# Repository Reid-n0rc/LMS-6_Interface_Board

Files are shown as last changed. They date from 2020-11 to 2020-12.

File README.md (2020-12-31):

# LMS-6_Interface_Board
Interface to the LMS-6 radiosonde carde edge connector.

This project provides an easy way to connect to the UARTs, in circuit programming of the ST7, and provide power to the LMS6 Radiosonde using a card edge connector.
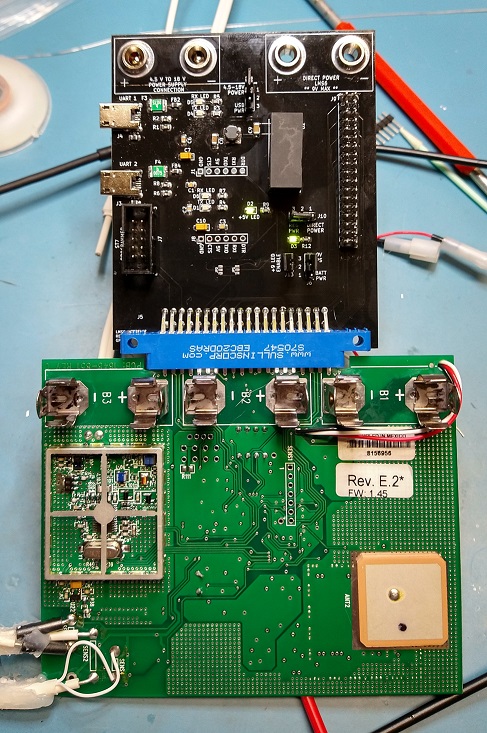
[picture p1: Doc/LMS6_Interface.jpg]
LMS6 and Interface

# Fabrication Notes
## Fabrication Files
File for fabrication are in (./Fabrication) directory.  This contains the gerber files and BOM
# Build Notes
## Minimum build
Depending on how you intend on using this board, many of the parts can be omitted. The minimal build provides a connection for the ST7 programmer and card edge interface. The LMS6 will be powered by the CR123 batteries installed on the LMS6.  This configuration requires J5, J6, J7, and one shunt connector (jumper).

J6 has pins 1 and 2 jumpered together to connect the battery power.  The shunt connector will allow the LMS6 to be turned on and off.

## 9V Regulated Supply

## 4.5V to 18V Supply

## UART1

## UART2
JP3 needs cut and the alternate postion soldered to receive data from the debugging port. Debugging seial is 8N1 at 500kbits/sec.

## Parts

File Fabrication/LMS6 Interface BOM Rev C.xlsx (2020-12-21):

Qty | Reference(s) | Value | Description | MPN | Manufacturer
4 | C1, C2, C3, C6 | 0.1uF | Multilayer Ceramic Capacitors MLCC - SMD/SMT 100nF+/-10% 50V X7R 2012 | CL21B104KBCNNNC | Samsung Electro-Mechanics
2 | C7, C10 | 10uF | Tantalum Capacitors - Solid SMD 10V 10uF 1206 10% ESR=4Ohms | T491A106K010AT | KEMET
1 | C8 | 10uF | Multilayer Ceramic Capacitors MLCC - SMD/SMT 10uF+/-10% 25V X5R 3216 | CL31A106KAHNNNE | Samsung Electro-Mechanics
1 | C9 | 4.7uF | 4.7µF ±10% 25V Ceramic Capacitor X7R 1206 (3216 Metric) | CL31B475KAHNNNE | Samsung Electro-Mechanics
6 | D1, D2, D3, D4, D5, D6 | LG R971-KN-1 | Green 570nm LED Indication - Discrete 2.2V 0805 (2012 Metric) | LG R971-KN-1 | OSRAM Opto Semiconductors Inc.
4 | E1, E2, E3, E4 | 575-6 | Banana Jack Connector Standard Banana Solder | 575-6 | Cinch Connectivity Solutions Johnson
4 | F1, F2, F3, F4 | 750mA | Polymeric PTC Resettable Fuse 16V 750mA Ih Surface Mount 1812 (4532 Metric), Concave | 0ZCG0075FF2C | Bel Fuse Inc.
4 | FB1, FB2, FB3, FB4 | MPZ2012S601AT000 | 600 Ohms @ 100MHz 1 Power Line Ferrite Bead 0805 (2012 Metric) 2A 100mOhm | MPZ2012S601AT000 | TDK Corporation
2 | J1, J8 | Conn_01x06 | Connector Header Through Hole 6 position 0.100" (2.54mm) | 5-146256-3 | TE Connectivity AMP Connectors
3 | J2, J6, J10 | Conn_01x03 | Connector Header Through Hole 3 position 0.100" (2.54mm) | 61300311121 | WÃ¼rth Elektronik
2 | J3, J4 | UJ2-MIBH-4-SMT-TR | Connector Header Through Hole 3 position 0.100" (2.54mm) | UJ2-MIBH-4-SMT-TR | CUI Inc.
1 | J5 | EBC20DRAS | 40 Position Female Connector Non Specified - Dual Edge Gold 0.100" (2.54mm) Blue | EBC20DRAS | Sullins Connector Solutions
1 | J7 | 302-S101 | Connector Header Through Hole 10 position 0.100" (2.54mm) | 302-S101 | On Shore Technology Inc.
1 | J9 | Conn_02x18_Odd_Even | Connector Header Through Hole 36 position 0.100" (2.54mm) | PREC018DAAN-RC | Sullins Connector Solutions
1 | J13 | Conn_01x02 | Connector Header Through Hole 2 position 0.100" (2.54mm) | 61300211121 | Würth Elektronik
1 | L1 | TCK-154 | 4.7µH Unshielded Inductor 1.15A 109mOhm Nonstandard | TCK-154 | Traco Power
4 | R1, R2, R6, R8 | 27 | 27 Ohms ±1% 0.125W, 1/8W Chip Resistor 0805 (2012 Metric) Thick Film | CRG0805F27R | TE Connectivity Passive Product
5 | R3, R4, R5, R7, R9 | 280 | 280 Ohms ±1% 0.125W, 1/8W Chip Resistor 0805 (2012 Metric) Thick Film | RC0805FR-07280RL | Yageo
1 | R12 | 909 | 909 Ohms ±1% 0.125W, 1/8W Chip Resistor 0805 (2012 Metric) Thick Film | RC0805FR-07909RL | Yageo
2 | U1, U3 | FT232RL-REEL | USB Bridge, USB to UART USB 2.0 UART Interface 28-SSOP | FT232RL-REEL | FTDI, Future Technology Devices International Ltd
1 | U2 | TEC2-1219WI | Isolated Module DC DC Converter 1 Output 9V 222mA 4.5V - 18V Input | TEC2-1219WI | TRACO Power
5 |  | NPC02SXON-RC | 2 (1 x 2) Position Shunt Connector Open Top, Grip 0.100" (2.54mm) Gold | NPC02SXON-RC | Sullins Connector Solutions

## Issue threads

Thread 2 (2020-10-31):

J7 Pin 1 indicator

Reid-n0rc, 2020-10-31:
J7 does not have a pin 1 indicator.

Reid-n0rc, 2020-11-30:
Corrected in the digikey library. Pull request sent to digikey to update their library. Corrected component used in #9

Closed 2020-11-30.

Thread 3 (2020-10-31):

J7 Footprint is configured so the J7 connector must be mounted on the back side of the PCB

Reid-n0rc, 2020-10-31:
J7 Footprint is configured so the J7 connector must be mounted on the back side of the PCB. This needs fixed.

Reid-n0rc, 2020-11-30:
Footprint corrected in the digikey library. Pull request sent to digikey.

Closed 2020-11-30.

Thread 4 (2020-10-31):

Create build documentation

Reid-n0rc, 2020-10-31:
Create construction guide. Include notes for fixing broken footprints.

Reid-n0rc, 2020-11-30:
Documentation will not be created for Rev B

Closed 2020-11-30.

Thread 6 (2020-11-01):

Cathode marking on LED is backward

Reid-n0rc, 2020-11-01:
Cathode mark On D2 silkscreen is on the wrong side

Reid-n0rc, 2020-11-07:
this applies to all LEDs

Reid-n0rc, 2020-11-30:
Markings corrected by assigning the correct footprint to the part in the digikey library. Pull request sent to digikey.

Closed 2020-11-30.

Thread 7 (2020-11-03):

J4 Pin 2 and 3 swapped

Reid-n0rc, 2020-11-03:
J4 Pin 2 should be IN_USBD_N on the schematic. J4 Pin 3 should be IN_USBD_P on the schematic.

Closed 2020-11-29.

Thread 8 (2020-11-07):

eFuse values not correct

Reid-n0rc, 2020-11-07:
eFuse limits at too low of current.

Reid-n0rc, 2020-11-30:
Values will not be corrected. Removed efuse for RTC fuse.

Closed 2020-11-30.

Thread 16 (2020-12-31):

9V direct backpowers the rest of the interface circuit

Reid-n0rc, 2020-12-31:
9V direct to the board backpowers the interface circuit. This will result in inaccurate power measurements and who knows what else. My guess is it's coming through the UART lines.

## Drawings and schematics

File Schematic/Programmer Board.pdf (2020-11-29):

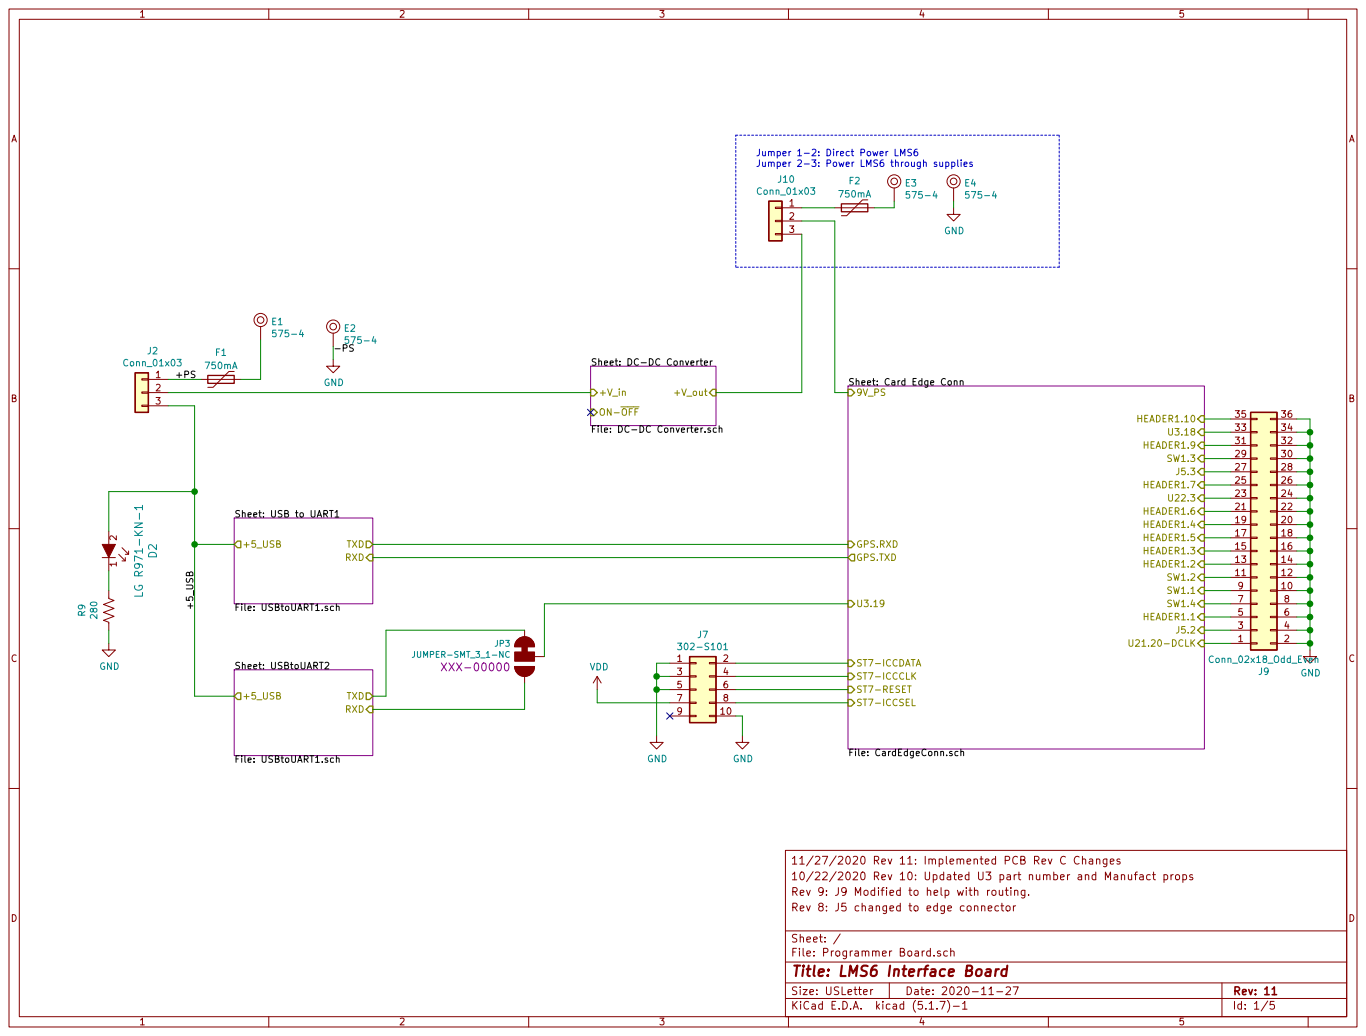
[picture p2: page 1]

Jumper 1-2: Direct Power LMS6
Jumper 2-3: Power LMS6 through supplies

33 | 34
31 | 32
29 | 30
27 | 28
25 | 26
23 | 24
21 | 22
19 | 20
17 | 18
15 | 16
13 | 14
11 | 12
9 | 10

10/22/2020 Rev 10: Updated U3 part number and Manufact props
Rev 9: J9 Modified to help with routing.
File: Programmer Board.sch Sheet: / Rev 8: J5 changed to edge connector

Id: 1/5 Title: LMS6 Interface Board

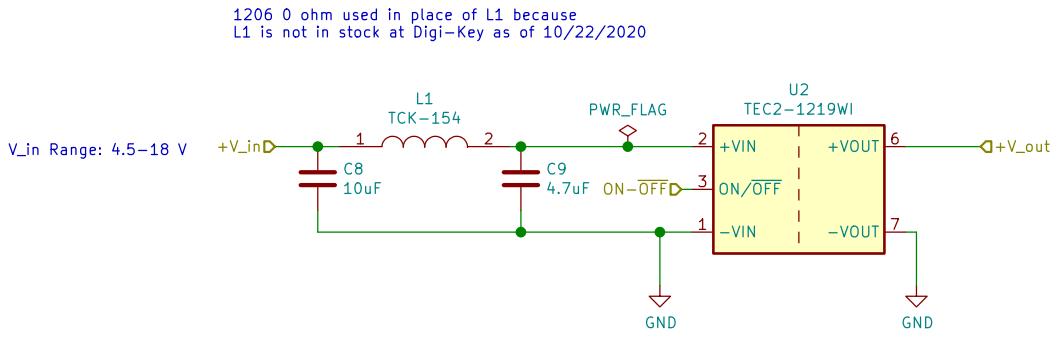
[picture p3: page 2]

L1 is not in stock at Digi-Key as of 10/22/2020

Id: 2/5 Title: DC-DC Converter File: DC-DC Converter.sch Sheet: /DC-DC Converter/

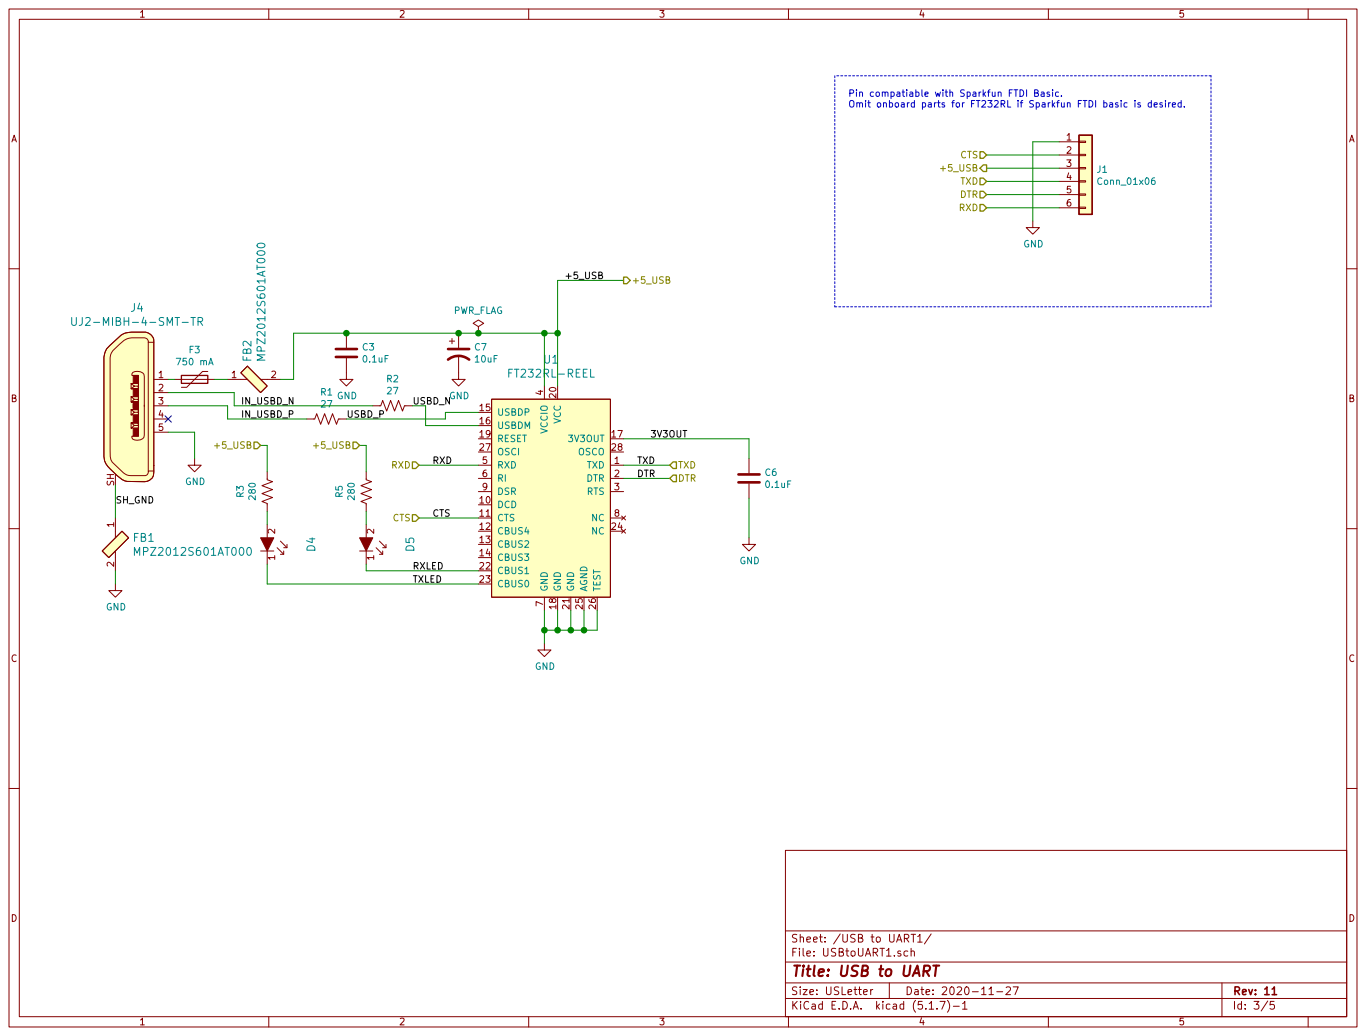
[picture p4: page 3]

Pin compatiable with Sparkfun FTDI Basic.
Omit onboard parts for FT232RL if Sparkfun FTDI basic is desired.

7 NC 8 DSR 9 DCD 10 VCC 20 CTS 11 GND 21 CBUS4 12 CBUS1 22 CBUS2 13 CBUS0 23 CBUS3 14 NC 24 USBDP 15 AGND 25 USBDM 16 TEST 26

Id: 3/5 Title: USB to UART

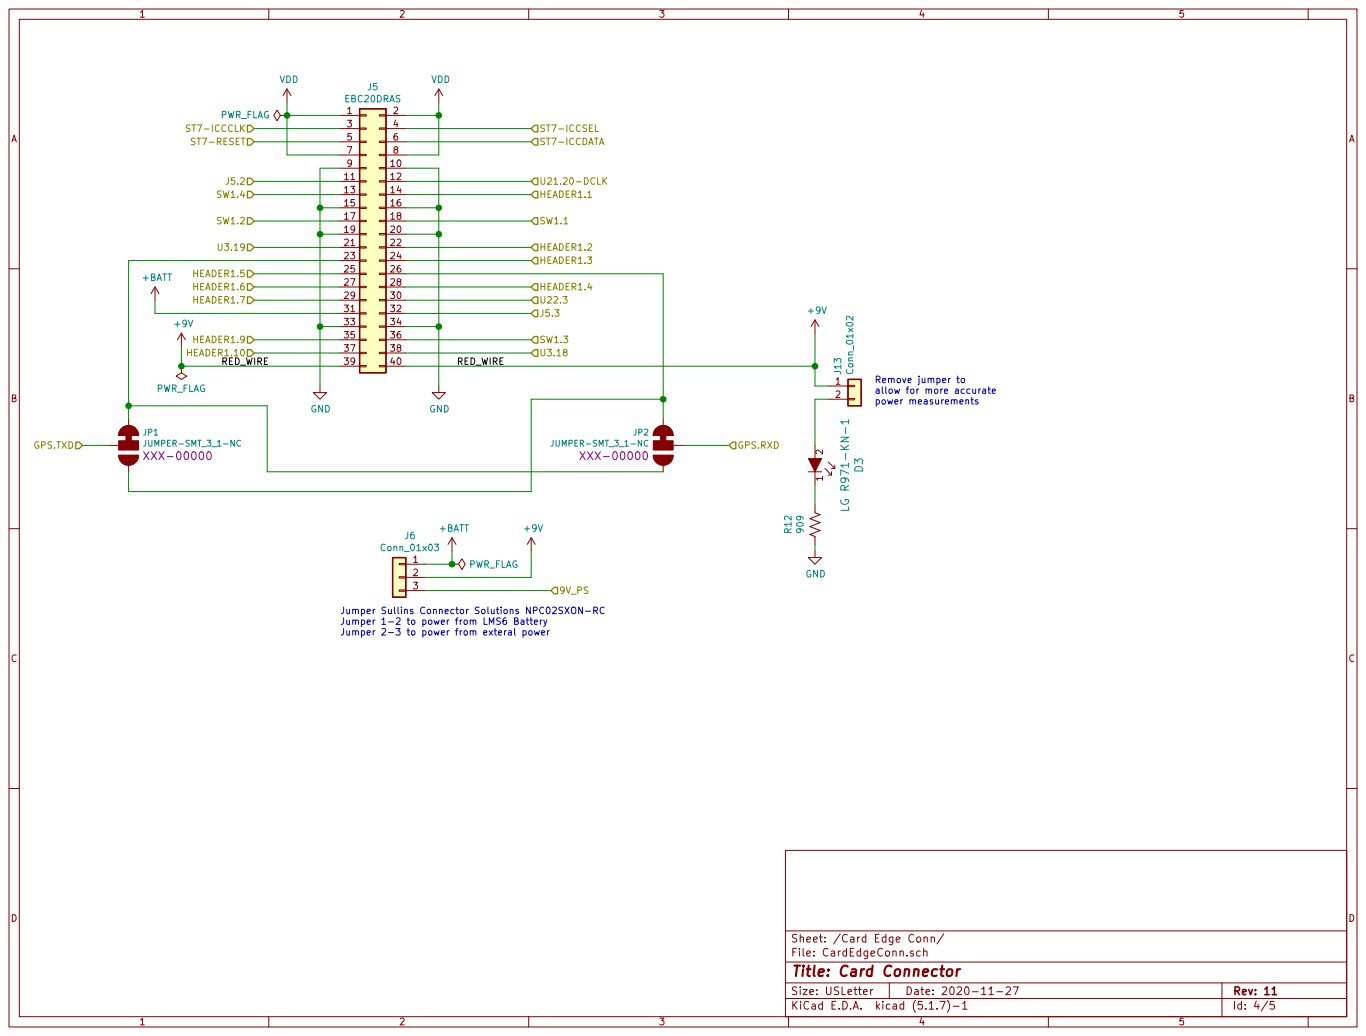
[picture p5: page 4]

Remove jumper to allow for more accurate

Jumper Sullins Connector Solutions NPC02SXON-RC
Jumper 1-2 to power from LMS6 Battery
Jumper 2-3 to power from exteral power

Sheet: /Card Edge Conn/
File: CardEdgeConn.sch
Id: 4/5 Title: Card Connector

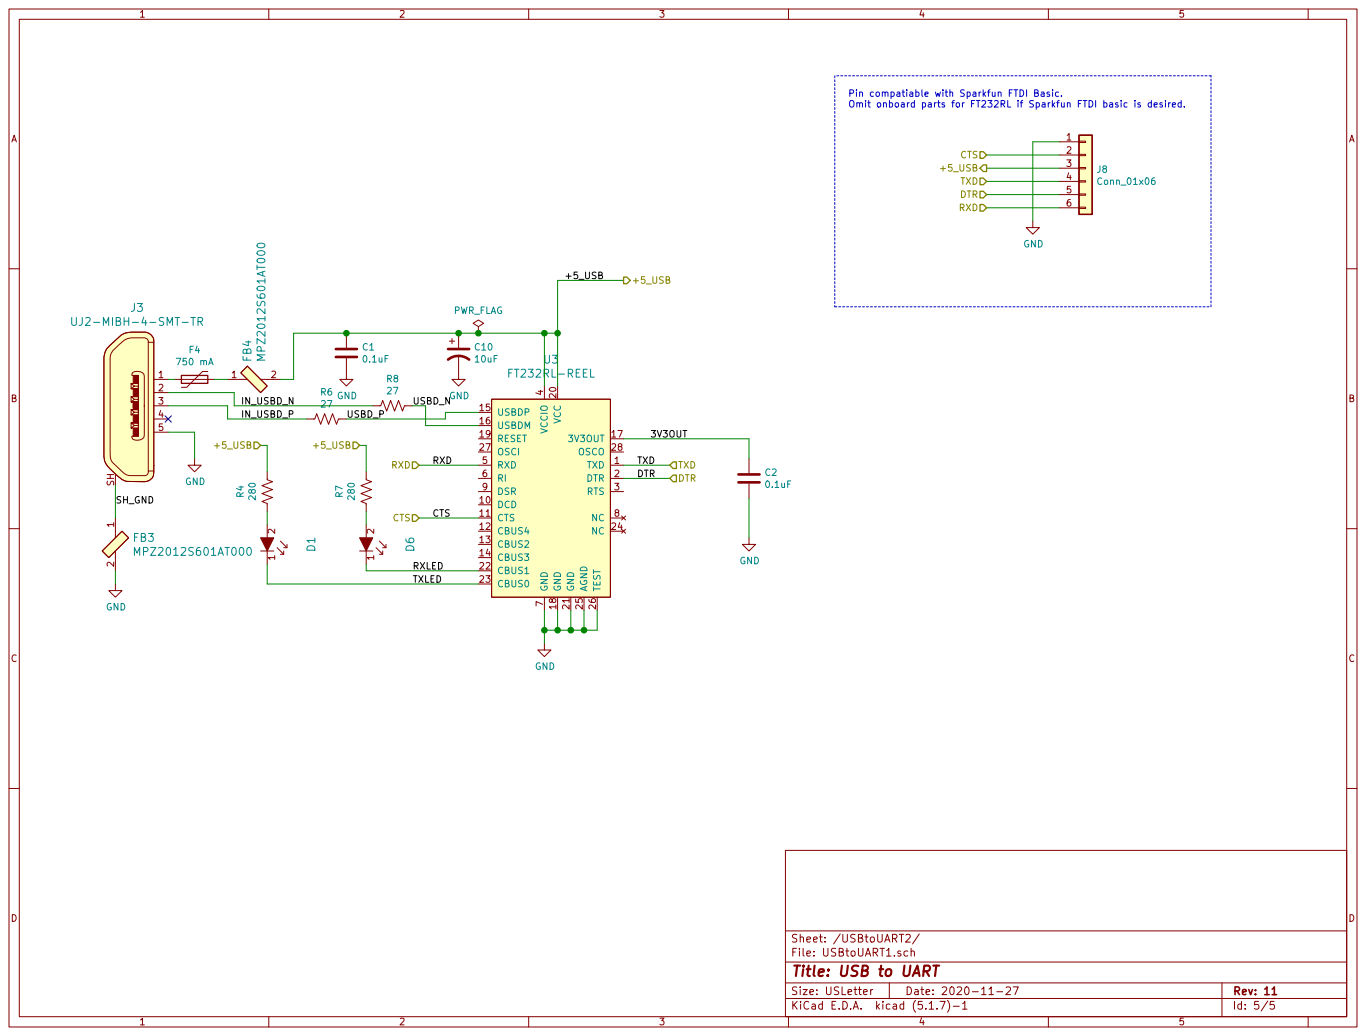
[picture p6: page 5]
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

Id: 5/5 Title: USB to UART

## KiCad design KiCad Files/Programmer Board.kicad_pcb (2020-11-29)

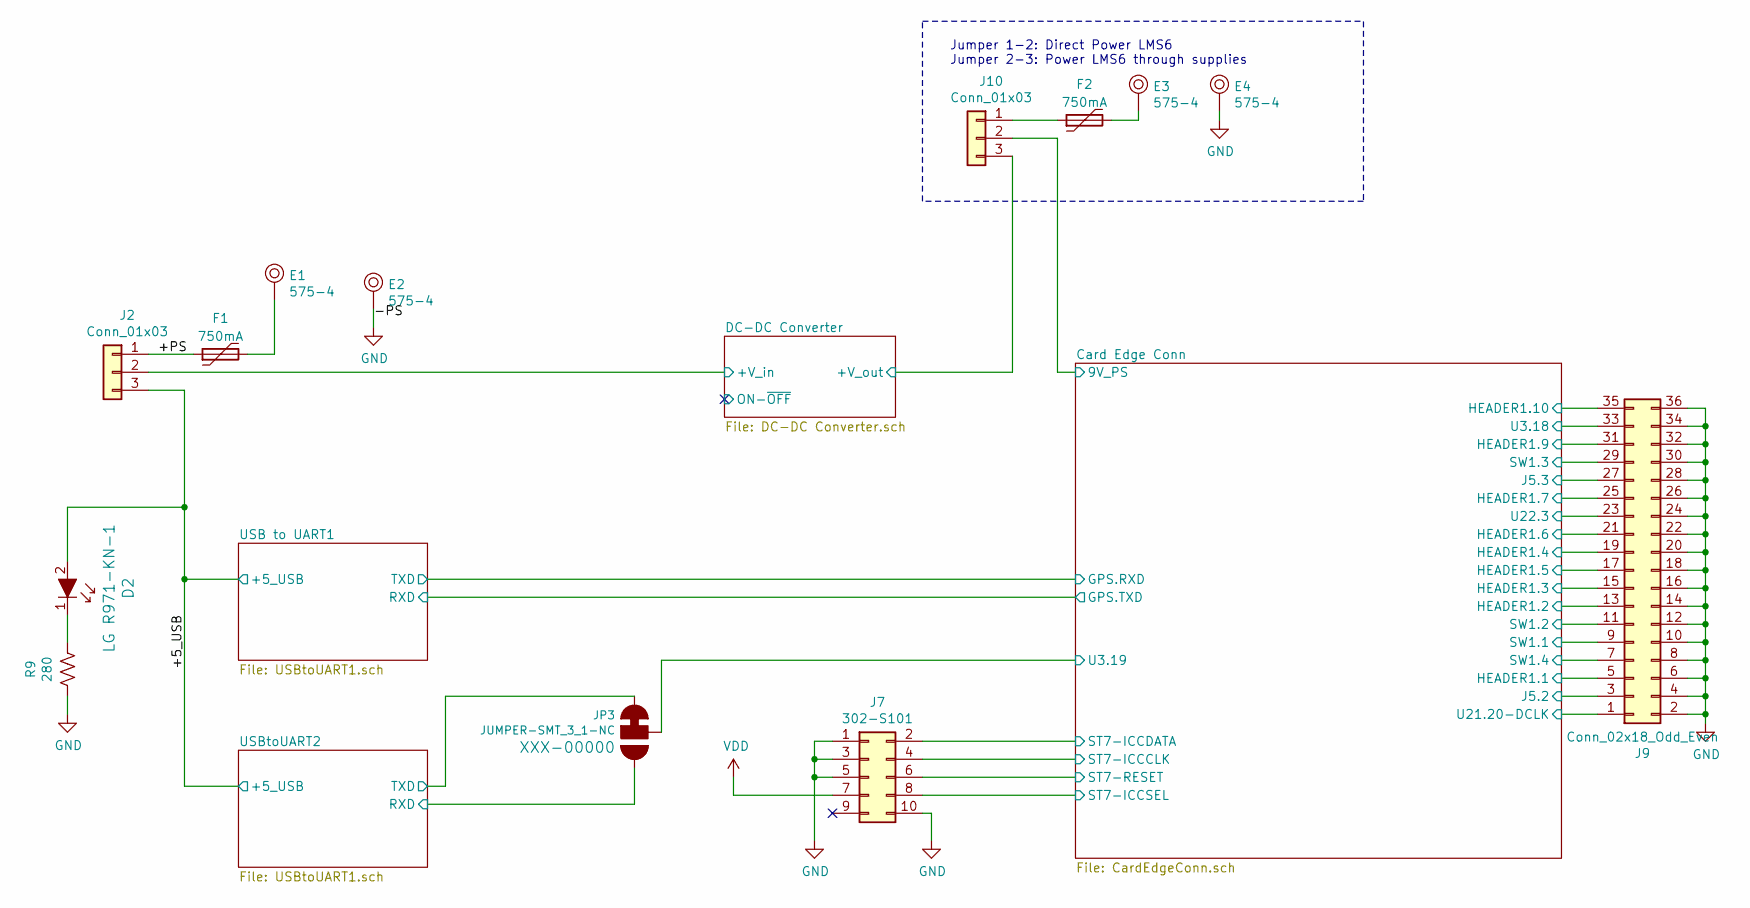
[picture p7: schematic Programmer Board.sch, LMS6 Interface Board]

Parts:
D2: LG R971-KN-1; LED_0805_2012Metric_Pad1.15x1.40mm_HandSolder; MPN LG R971-KN-1; Digi-Key_PN 475-1410-1-ND
E1, E3: 575-4; 575_Banana_Jack; MPN 575-4; Digi-Key_PN 36-575-4-ND
E2: 575-4; 575_Banana_Jack; MPN 105-1103-001; Digi-Key_PN 36-575-4-ND
E4: 575-4; 575_Banana_Jack; MPN 36-575-4-ND; Digi-Key_PN J577-ND
F1, F2: 750mA; R_1812_4532Metric_Pad1.30x3.40mm_HandSolder; MPN 0ZCG0075FF2C
J2, J10: Conn_01x03; PinHeader_1x03_P2.54mm_Vertical; MPN 61300311121
J7: 302-S101; PinHeader_2x5_P2.54mm_Drill1.02mm; MPN 302-S101
J9: Conn_02x18_Odd_Even; PinHeader_2x18_P2.54mm_Vertical; MPN PREC018DAAN-RC
JP3: JUMPER-SMT_3_1-NC; SMT-JUMPER_3_1-NC_TRACE_NO-SILK
R9: 280; R_0805_2012Metric_Pad1.20x1.40mm_HandSolder; MPN RC0805FR-07280RL

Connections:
/+5_USB: D2.2, J2.3; also elsewhere on the board
/+PS: F1.1, J2.1
/Card Edge Conn/9V_PS: J10.2; also elsewhere on the board
/Card Edge Conn/HEADER1.1: J9.5; also elsewhere on the board
/Card Edge Conn/HEADER1.2: J9.13; also elsewhere on the board
/Card Edge Conn/HEADER1.3: J9.15; also elsewhere on the board
/Card Edge Conn/HEADER1.4: J9.19; also elsewhere on the board
/Card Edge Conn/HEADER1.5: J9.17; also elsewhere on the board
/Card Edge Conn/HEADER1.6: J9.21; also elsewhere on the board
/Card Edge Conn/HEADER1.7: J9.25; also elsewhere on the board
/Card Edge Conn/HEADER1.9: J9.31; also elsewhere on the board
/Card Edge Conn/HEADER1.10: J9.35; also elsewhere on the board
/Card Edge Conn/J5.2: J9.3; also elsewhere on the board
/Card Edge Conn/J5.3: J9.27; also elsewhere on the board
/Card Edge Conn/ST7-ICCCLK: J7.4; also elsewhere on the board
/Card Edge Conn/ST7-ICCDATA: J7.2; also elsewhere on the board
/Card Edge Conn/ST7-ICCSEL: J7.8; also elsewhere on the board
/Card Edge Conn/ST7-RESET: J7.6; also elsewhere on the board
/Card Edge Conn/SW1.1: J9.9; also elsewhere on the board
/Card Edge Conn/SW1.2: J9.11; also elsewhere on the board
/Card Edge Conn/SW1.3: J9.29; also elsewhere on the board
/Card Edge Conn/SW1.4: J9.7; also elsewhere on the board
/Card Edge Conn/U3.18: J9.33; also elsewhere on the board
/Card Edge Conn/U3.19: JP3.2; also elsewhere on the board
/Card Edge Conn/U21.20-DCLK: J9.1; also elsewhere on the board
/Card Edge Conn/U22.3: J9.23; also elsewhere on the board
/DC-DC Converter/+V_in: J2.2; also elsewhere on the board
/DC-DC Converter/+V_out: J10.3; also elsewhere on the board
/sheet5FC8868D/RXD: JP3.1; also elsewhere on the board
/sheet5FC8868D/TXD: JP3.3; also elsewhere on the board
GND: E2.1, E4.1, J7.1, J7.3, J7.5, J7.10, J9.2, J9.4, J9.6, J9.8, J9.10, J9.12, J9.14, J9.16, J9.18, J9.20, J9.22, J9.24, J9.26, J9.28, J9.30, J9.32, J9.34, J9.36, R9.2; also elsewhere on the board
unnamed: D2.1, R9.1
unnamed: E1.1, F1.2
unnamed: E3.1, F2.2
unnamed: F2.1, J10.1
VDD: J7.7; also elsewhere on the board

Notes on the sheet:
Jumper 1-2: Direct Power LMS6 Jumper 2-3: Power LMS6 through supplies

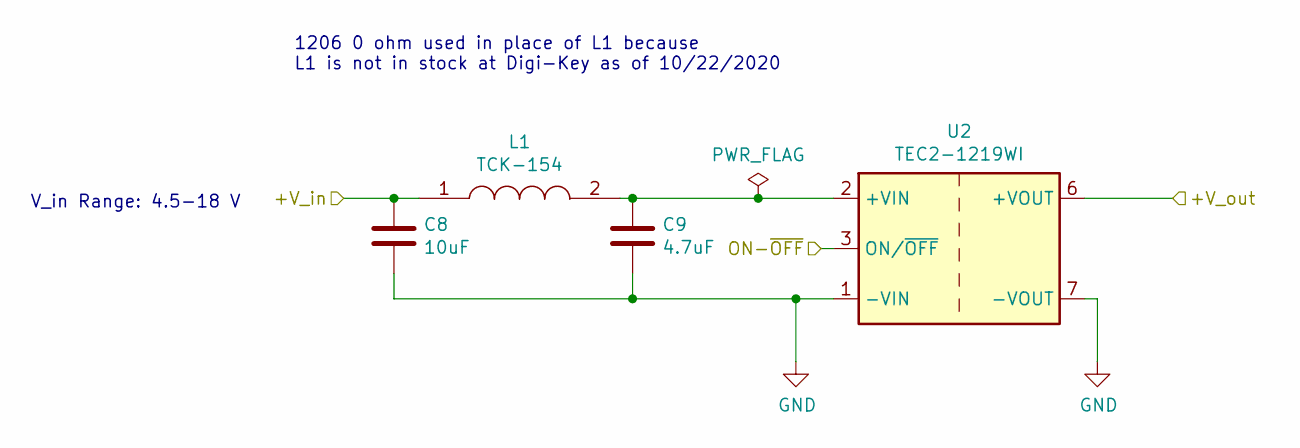
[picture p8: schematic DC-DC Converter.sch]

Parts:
C8: 10uF; C_1206_3216Metric_Pad1.33x1.80mm_HandSolder; MPN CL31A106KAHNNNE
C9: 4.7uF; C_1206_3216Metric_Pad1.33x1.80mm_HandSolder; MPN CL31B475KAHNNNE
L1: TCK-154; TCK154; Mouser Part Number 495-TCK-154
U2: TEC2-1219WI; Converter_DCDC_TRACO_TMR-xxxx_THT

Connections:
/DC-DC Converter/+V_in: C8.1, L1.1; also elsewhere on the board
/DC-DC Converter/+V_out: U2.6 (+VOUT); also elsewhere on the board
GND: C8.2, C9.2, U2.1 (-VIN), U2.7 (-VOUT); also elsewhere on the board
unnamed: C9.1, L1.2, U2.2 (+VIN)

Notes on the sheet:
V_in Range: 4.5-18 V
1206 0 ohm used in place of L1 because L1 is not in stock at Digi-Key as of 10/22/2020

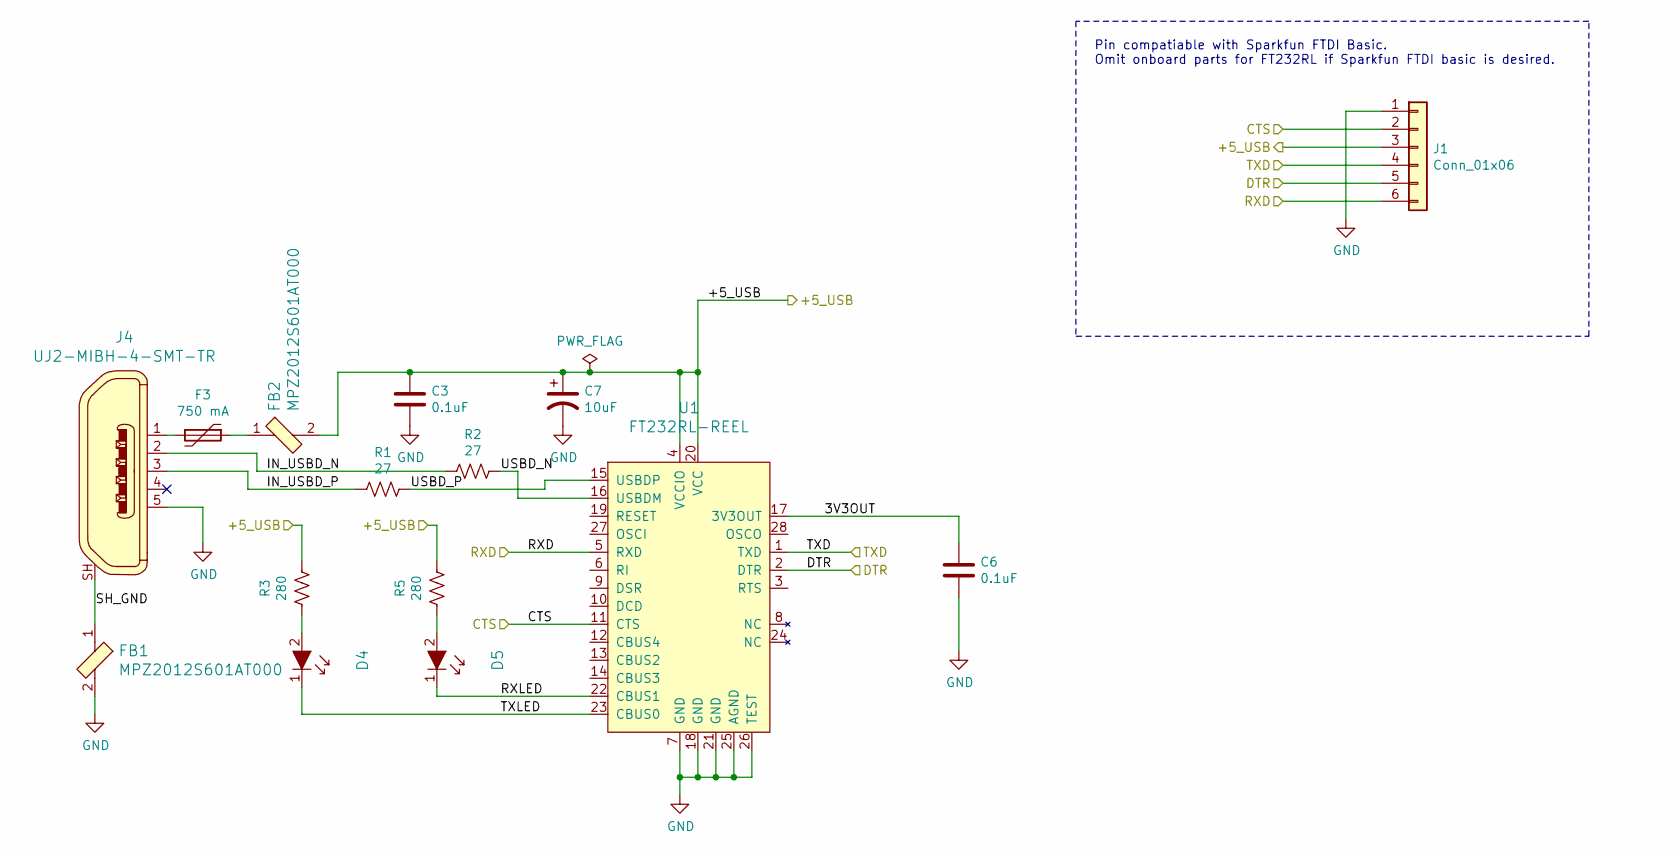
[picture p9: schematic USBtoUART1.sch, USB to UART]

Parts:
C3, C6: 0.1uF; C_0805_2012Metric_Pad1.18x1.45mm_HandSolder; MPN CL21B104KBCNNNC
C7: 10uF; CP_EIA-3216-10_Kemet-I_Pad1.58x1.35mm_HandSolder; MPN T491A106K010AT
D4, D5: LG R971-KN-1; LED_0805_2012Metric_Pad1.15x1.40mm_HandSolder; MPN LG R971-KN-1; Digi-Key_PN 475-1410-1-ND
F3: 750 mA; R_1812_4532Metric_Pad1.30x3.40mm_HandSolder; MPN 0ZCG0075FF2C
FB1, FB2: MPZ2012S601AT000; 0805; MPN MPZ2012S601AT000; Digi-Key_PN 445-2206-1-ND
J1: Conn_01x06; PinHeader_1x06_P2.54mm_Vertical; MPN 5-146256-3
J4: UJ2-MIBH-4-SMT-TR; USB_Micro_B_Male_UJ2-MIBH-4-SMT-TR; MPN UJ2-MIBH-4-SMT-TR; Digi-Key_PN 102-4006-1-ND
R1, R2: 27; R_0805_2012Metric_Pad1.20x1.40mm_HandSolder; MPN CRG0805F27R
R3, R5: 280; R_0805_2012Metric_Pad1.20x1.40mm_HandSolder; MPN RC0805FR-07280RL
U1: FT232RL-REEL; SSOP-28_W5.30mm; MPN FT232RL-REEL; Digi-Key_PN 768-1007-1-ND

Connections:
/+5_USB: C3.1, C7.1, FB2.2, J1.3, R3.1, R5.1, U1.4 (VCCIO), U1.20 (VCC); also elsewhere on the board
/Card Edge Conn/GPS.RXD: J1.4, U1.1 (TXD); also elsewhere on the board
/Card Edge Conn/GPS.TXD: J1.6, U1.5 (RXD); also elsewhere on the board
/USB to UART1/3V3OUT: C6.1, U1.17 (3V3OUT)
/USB to UART1/CTS: J1.2, U1.11 (CTS)
/USB to UART1/DTR: J1.5, U1.2 (DTR)
/USB to UART1/IN_USBD_N: J4.2, R2.2
/USB to UART1/IN_USBD_P: J4.3, R1.2
/USB to UART1/RXLED: D5.1, U1.22 (CBUS1)
/USB to UART1/SH_GND: FB1.1, J4.SH
/USB to UART1/TXLED: D4.1, U1.23 (CBUS0)
/USB to UART1/USBD_N: R2.1, U1.16 (USBDM)
/USB to UART1/USBD_P: R1.1, U1.15 (USBDP)
GND: C3.2, C6.2, C7.2, FB1.2, J1.1, J4.5, U1.7 (GND), U1.18 (GND), U1.21 (GND), U1.25 (AGND), U1.26 (TEST); also elsewhere on the board
unnamed: D4.2, R3.2
unnamed: D5.2, R5.2
unnamed: F3.1, FB2.1
unnamed: F3.2, J4.1

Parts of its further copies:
C1, C2: 0.1uF; C_0805_2012Metric_Pad1.18x1.45mm_HandSolder; MPN CL21B104KBCNNNC
C10: 10uF; CP_EIA-3216-10_Kemet-I_Pad1.58x1.35mm_HandSolder; MPN T491A106K010AT
D1, D6: LG R971-KN-1; LED_0805_2012Metric_Pad1.15x1.40mm_HandSolder; MPN LG R971-KN-1; Digi-Key_PN 475-1410-1-ND
F4: 750 mA; R_1812_4532Metric_Pad1.30x3.40mm_HandSolder; MPN 0ZCG0075FF2C
FB3, FB4: MPZ2012S601AT000; 0805; MPN MPZ2012S601AT000; Digi-Key_PN 445-2206-1-ND
J3: UJ2-MIBH-4-SMT-TR; USB_Micro_B_Male_UJ2-MIBH-4-SMT-TR; MPN UJ2-MIBH-4-SMT-TR; Digi-Key_PN 102-4006-1-ND
J8: Conn_01x06; PinHeader_1x06_P2.54mm_Vertical; MPN 5-146256-3
R4, R7: 280; R_0805_2012Metric_Pad1.20x1.40mm_HandSolder; MPN RC0805FR-07280RL
R6, R8: 27; R_0805_2012Metric_Pad1.20x1.40mm_HandSolder; MPN CRG0805F27R
U3: FT232RL-REEL; SSOP-28_W5.30mm; MPN FT232RL-REEL; Digi-Key_PN 768-1007-1-ND

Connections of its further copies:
/+5_USB: C1.1, C10.1, FB4.2, J8.3, R4.1, R7.1, U3.4 (VCCIO), U3.20 (VCC); also elsewhere on the board
/sheet5FC8868D/3V3OUT: C2.1, U3.17 (3V3OUT)
/sheet5FC8868D/CTS: J8.2, U3.11 (CTS)
/sheet5FC8868D/DTR: J8.5, U3.2 (DTR)
/sheet5FC8868D/IN_USBD_N: J3.2, R8.2
/sheet5FC8868D/IN_USBD_P: J3.3, R6.2
/sheet5FC8868D/RXD: J8.6, U3.5 (RXD); also elsewhere on the board
/sheet5FC8868D/RXLED: D6.1, U3.22 (CBUS1)
/sheet5FC8868D/SH_GND: FB3.1, J3.SH
/sheet5FC8868D/TXD: J8.4, U3.1 (TXD); also elsewhere on the board
/sheet5FC8868D/TXLED: D1.1, U3.23 (CBUS0)
/sheet5FC8868D/USBD_N: R8.1, U3.16 (USBDM)
/sheet5FC8868D/USBD_P: R6.1, U3.15 (USBDP)
GND: C1.2, C2.2, C10.2, FB3.2, J3.5, J8.1, U3.7 (GND), U3.18 (GND), U3.21 (GND), U3.25 (AGND), U3.26 (TEST); also elsewhere on the board
unnamed: D1.2, R4.2
unnamed: D6.2, R7.2
unnamed: F4.1, FB4.1
unnamed: F4.2, J3.1

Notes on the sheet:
Pin compatiable with Sparkfun FTDI Basic. Omit onboard parts for FT232RL if Sparkfun FTDI basic is desired.

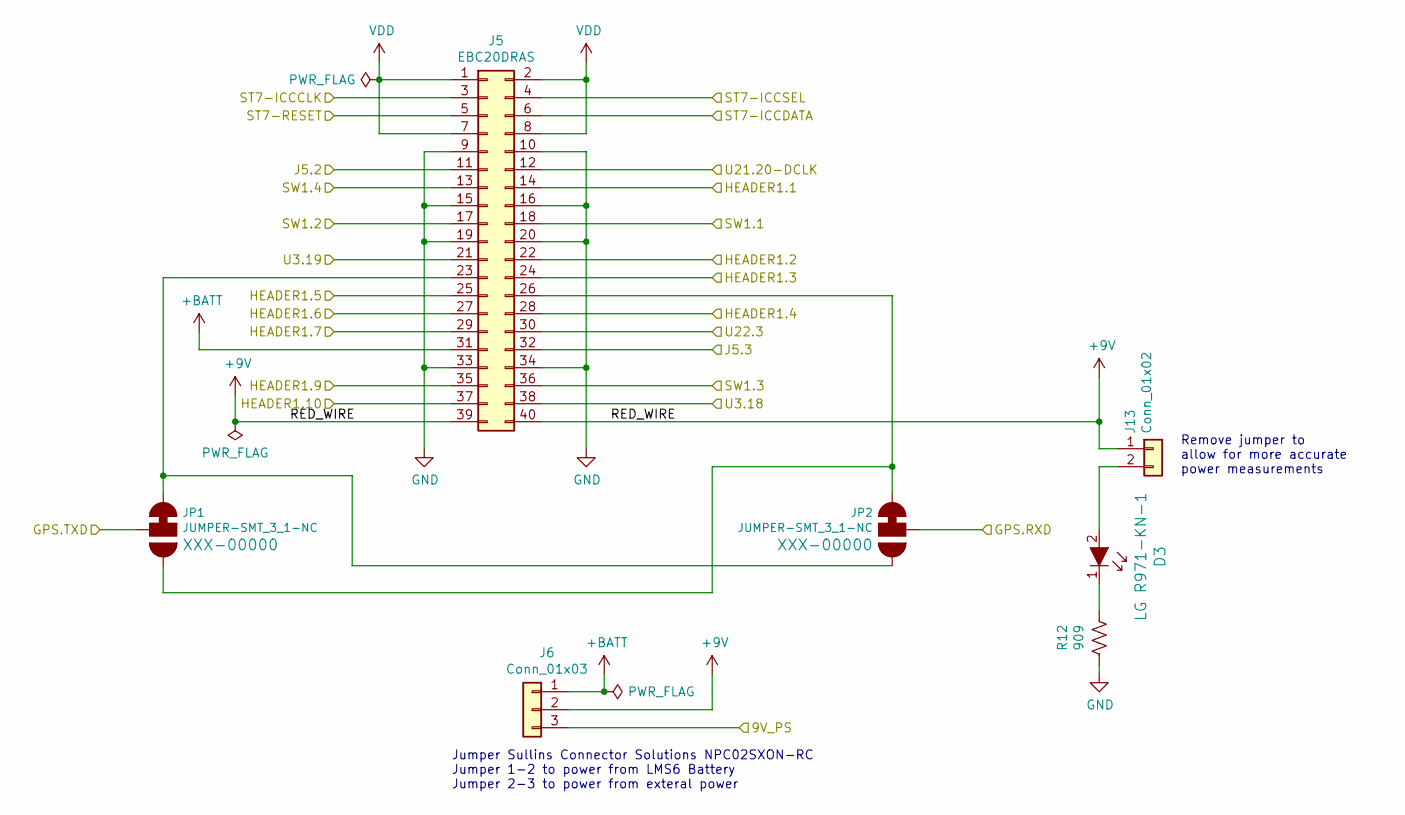
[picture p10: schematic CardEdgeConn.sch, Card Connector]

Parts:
D3: LG R971-KN-1; LED_0805_2012Metric_Pad1.15x1.40mm_HandSolder; MPN LG R971-KN-1; Digi-Key_PN 475-1410-1-ND
J5: EBC20DRAS
J6: Conn_01x03; PinHeader_1x03_P2.54mm_Vertical; MPN 61300311121
J13: Conn_01x02; PinHeader_1x02_P2.54mm_Vertical; MPN 61300211121
JP1, JP2: JUMPER-SMT_3_1-NC; SMT-JUMPER_3_1-NC_TRACE_NO-SILK
R12: 909; R_0805_2012Metric_Pad1.20x1.40mm_HandSolder; MPN RC0805FR-07909RL

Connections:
+9V: J5.39, J5.40, J6.2, J13.1
+BATT: J5.31, J6.1
/Card Edge Conn/9V_PS: J6.3; also elsewhere on the board
/Card Edge Conn/GPS.RXD: JP2.2; also elsewhere on the board
/Card Edge Conn/GPS.TXD: JP1.2; also elsewhere on the board
/Card Edge Conn/HEADER1.1: J5.14; also elsewhere on the board
/Card Edge Conn/HEADER1.2: J5.22; also elsewhere on the board
/Card Edge Conn/HEADER1.3: J5.24; also elsewhere on the board
/Card Edge Conn/HEADER1.4: J5.28; also elsewhere on the board
/Card Edge Conn/HEADER1.5: J5.25; also elsewhere on the board
/Card Edge Conn/HEADER1.6: J5.27; also elsewhere on the board
/Card Edge Conn/HEADER1.7: J5.29; also elsewhere on the board
/Card Edge Conn/HEADER1.9: J5.35; also elsewhere on the board
/Card Edge Conn/HEADER1.10: J5.37; also elsewhere on the board
/Card Edge Conn/J5.2: J5.11; also elsewhere on the board
/Card Edge Conn/J5.3: J5.32; also elsewhere on the board
/Card Edge Conn/ST7-ICCCLK: J5.3; also elsewhere on the board
/Card Edge Conn/ST7-ICCDATA: J5.6; also elsewhere on the board
/Card Edge Conn/ST7-ICCSEL: J5.4; also elsewhere on the board
/Card Edge Conn/ST7-RESET: J5.5; also elsewhere on the board
/Card Edge Conn/SW1.1: J5.18; also elsewhere on the board
/Card Edge Conn/SW1.2: J5.17; also elsewhere on the board
/Card Edge Conn/SW1.3: J5.36; also elsewhere on the board
/Card Edge Conn/SW1.4: J5.13; also elsewhere on the board
/Card Edge Conn/U3.18: J5.38; also elsewhere on the board
/Card Edge Conn/U3.19: J5.21; also elsewhere on the board
/Card Edge Conn/U21.20-DCLK: J5.12; also elsewhere on the board
/Card Edge Conn/U22.3: J5.30; also elsewhere on the board
GND: J5.9, J5.10, J5.15, J5.16, J5.19, J5.20, J5.33, J5.34, R12.2; also elsewhere on the board
unnamed: D3.1, R12.1
unnamed: D3.2, J13.2
unnamed: J5.23, JP1.3, JP2.1
unnamed: J5.26, JP1.1, JP2.3
VDD: J5.1, J5.2, J5.7, J5.8; also elsewhere on the board

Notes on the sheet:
Jumper Sullins Connector Solutions NPC02SXON-RC Jumper 1-2 to power from LMS6 Battery Jumper 2-3 to power from exteral power
Remove jumper to allow for more accurate power measurements

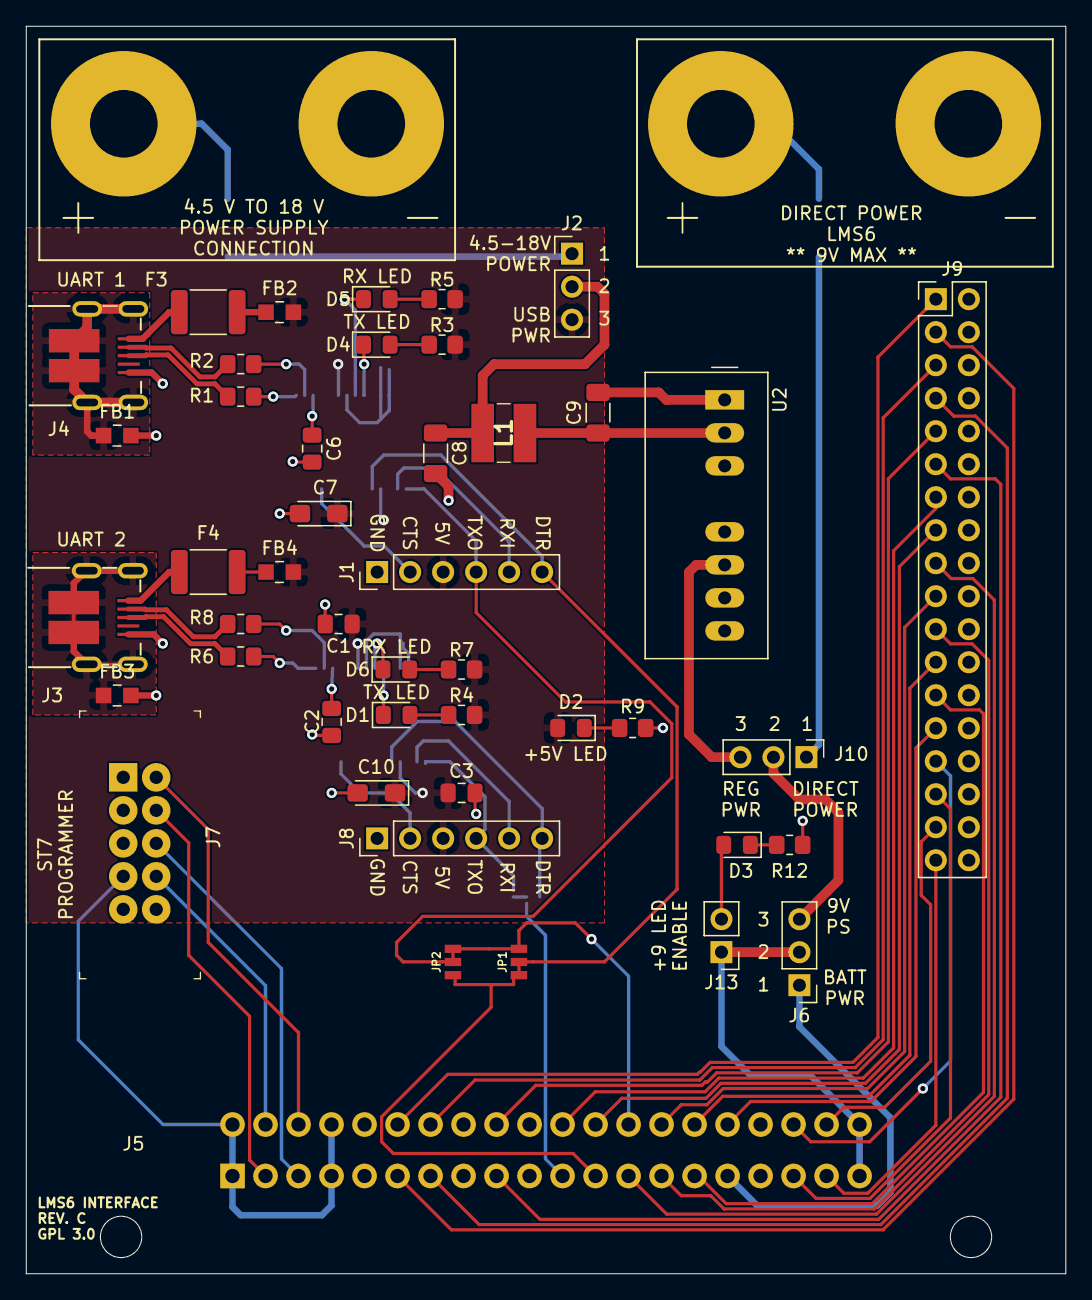
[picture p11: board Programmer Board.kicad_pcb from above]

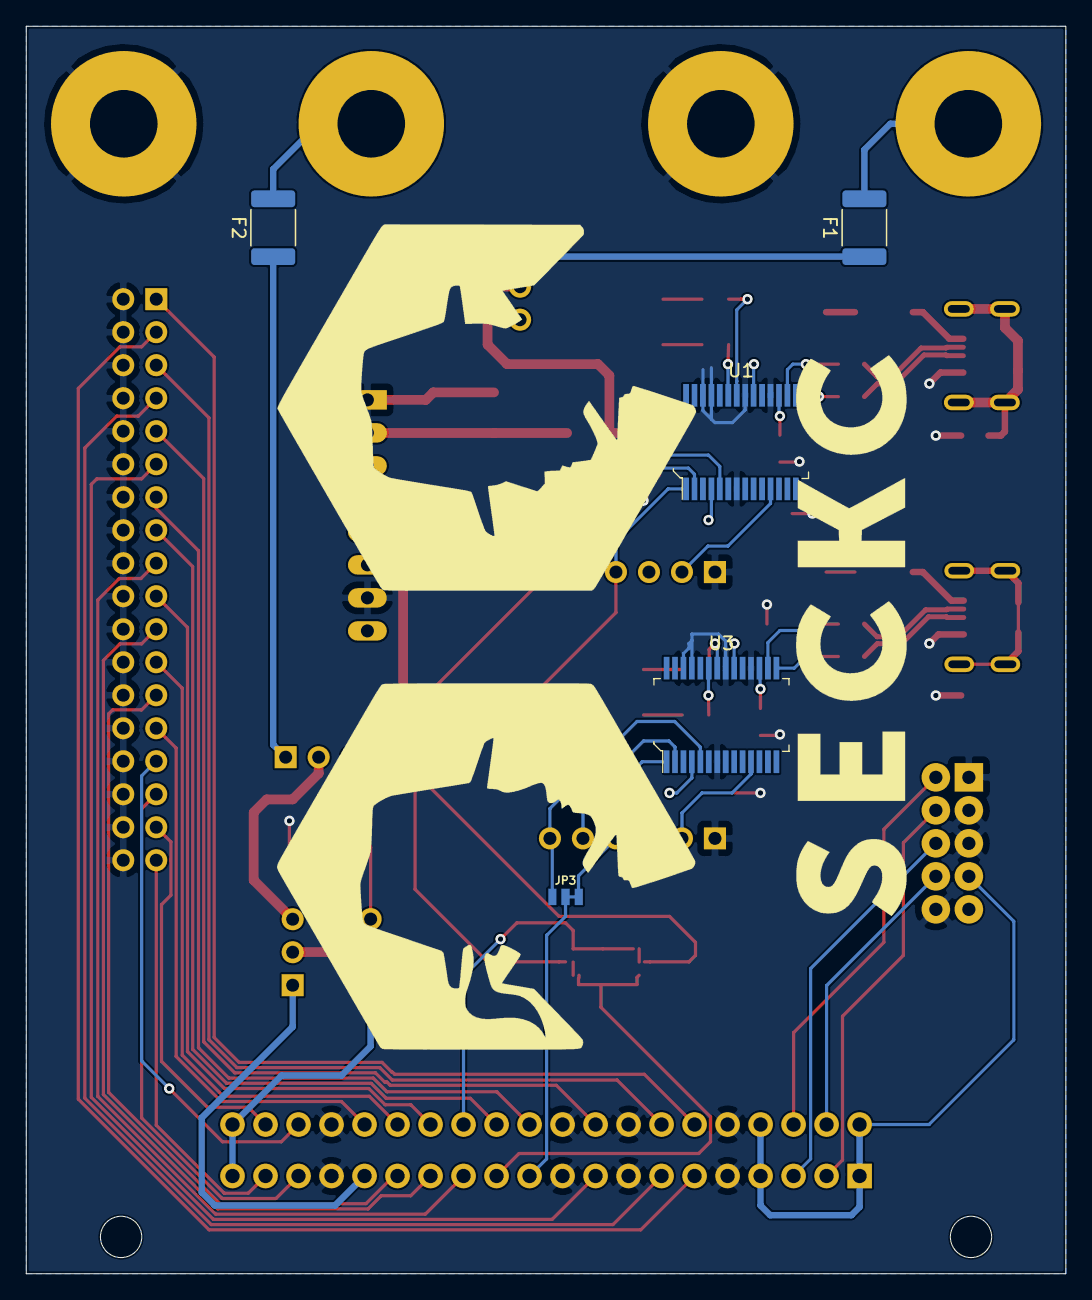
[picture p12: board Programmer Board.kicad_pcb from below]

Board: 2 copper layers, 80.0 x 96.0 mm, 54 parts (5 on the bottom side), 73 nets.

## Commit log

2020-10-06 Commit of Programmer Board Files
    Initial commit of all the KiCad files
    [Card Edge Conn.sch, CardEdgeConn.sch, Programmer Board.kicad_pcb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]
2020-10-16 Added DC-DC converter
    [CardEdgeConn.sch, DC-DC Converter.sch, Programmer Board.sch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]
2020-10-16 Added libraries used in the project. Top level connections.
    Added libraries used in this project to the project folder.
    Made additonal top level connections on the top level schematic.
    [CardEdgeConn.sch, DC-DC Converter.sch, Programmer Board.sch]
2020-10-16 Delete Card Edge Conn.sch
    This was an early attempt that is not needed.
    [Card Edge Conn.sch]
2020-10-16 Updated EdgeCardConn.sch with GPS UART
    Confiremed the GPS UART pins from discord chat.
    [CardEdgeConn.sch]
2020-10-16 Annotated schematics and added UART Jumpers
    Annotated schematics.
    Added jumpers to GPS UART because I'm still not 100% sure on the connections and I don't want to have to respin a board because I was wrong.
    [CardEdgeConn.sch, DC-DC Converter.sch, Programmer Board.sch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]
2020-10-17 completed connections
    [Programmer Board.sch, USBtoUART.sch]
2020-10-17 eFuse added
    Added eFuse, LEDs, and addtional power configuration options.
    [CardEdgeConn.sch, DC-DC Converter.sch, Programmer Board.sch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]
2020-10-17 Change Sheets to US Letter
    [CardEdgeConn.sch, DC-DC Converter.sch, Programmer Board.sch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]
2020-10-17 Fixed J9 hanging over edge of sheet
    [Programmer Board.sch]
2020-10-17 Fixed J6 footprint and MPN info
    [CardEdgeConn.sch, Programmer Board.sch]
2020-10-17 Updated rev number on all sheets
    [CardEdgeConn.sch, DC-DC Converter.sch, USBtoUART.sch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]
2020-10-17 Changed J9 connections to help with layout.
    [CardEdgeConn.sch, Programmer Board.sch, USBtoUART.sch]
2020-10-17 Initial pcb commit.
    [Programmer Board.kicad_pcb]
2020-10-18 Changed crystal for resonator. Board Layout.
    [CardEdgeConn.sch, DC-DC Converter.sch, Programmer Board.kicad_pcb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]
2020-10-18 Fixed DRC Errors
    Fixed drc errors
    [CardEdgeConn.sch, DC-DC Converter.sch, Programmer Board.kicad_pcb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]
2020-10-18 Fabrication outputs
    Added fabrication outputs
    [Programmer Board-B_Cu.GBL, Programmer Board-B_Mask.GBS, Programmer Board-B_Paste.gbr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]
2020-10-18 Added SecKC Logo
    [Programmer Board.kicad_pcb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]
2020-10-18 Adjustment to logo placement
    [Programmer Board.kicad_pcb]
2020-10-18 Fixing component field names, because I can't spell.
    [DC-DC Converter.sch, USBtoUART.sch]
2020-10-18 Create Interface Board BOM Rev A.xlsx
    [Interface Board BOM Rev A.xlsx]
2020-10-22 Final updates to REV B
    [CardEdgeConn.sch, DC-DC Converter.sch, Interface Board BOM Rev A.xlsx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]
2020-10-22 Reorganzied the included symbol and footprint libraries
2020-10-30 Added product info and Schematic
    [DC-DC Converter.sch, Programmer Board.sch, eFuse.sch]
2020-11-10 Fixed USB pins
    Fixed USB pin swap. Closes #7
    [USBtoUART.sch]
2020-11-28 Rev C Board layout
    [CardEdgeConn.sch, DC-DC Converter.sch, Programmer Board.kicad_pcb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]
2020-11-29 Rev C PCB as sent to fabrication
    REV C PCB as sent to fabrication with clean up directory structure.
    [CardEdgeConn.sch, DC-DC Converter.sch, Interface Board BOM Rev A.xlsx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]
2020-11-29 Updated fabrication output
    [Programmer Board-B_Cu.gbl, Programmer Board-B_Fab.gbr, Programmer Board-B_Mask.gbs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]
2020-11-29 Main directory cleanup
    main directory cleanup. Moved KiCad project files into KiCad folder
    [CardEdgeConn.sch, DC-DC Converter.sch, Programmer Board.kicad_pcb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]
2020-11-29 More KiCad cleanup
    [USBtoUART1.sch, USBtoUART2.sch, eFuse.sch]
2020-12-13 Updated part numbers to match
    Updated part numbers on components to fix errors.
    [CardEdgeConn.sch, DC-DC Converter.sch, Programmer Board.sch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]
2020-12-20 Created BOM for LMS6 Interface board Rev C
    Created BOM for LMS6 Interface board Rev C
    [LMS6 Interface BOM Rev C.xlsx]
2020-12-21 Update LMS6 Interface BOM Rev C.xlsx
    [LMS6 Interface BOM Rev C.xlsx]

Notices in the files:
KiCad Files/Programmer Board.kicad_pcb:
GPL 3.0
